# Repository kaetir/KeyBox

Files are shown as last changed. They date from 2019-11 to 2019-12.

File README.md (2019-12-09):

# KeyBox

## Équipe

- Antoine VERSMESSEN
- Clément DUQUENNE
- Édouard DANSETTE
- Sébastien WILLEMETZ
- Thibault DESPREZ

## Idées

*gestionnaire de mot de passe physique*

- Utiliser un raspi 0w si possible + usb board
- Écran
    - Oled
- Authentification 
    - Boutons 
    - Lecteur d'empreintes
- Navigation 
    - Boutons

On branche le raspi sur un pc ou un tel pour entrer le mot de passe en auto

Ajout des mots de passe par wifi et/ou physique

Stockage des mots de passe chiffré dans un Json

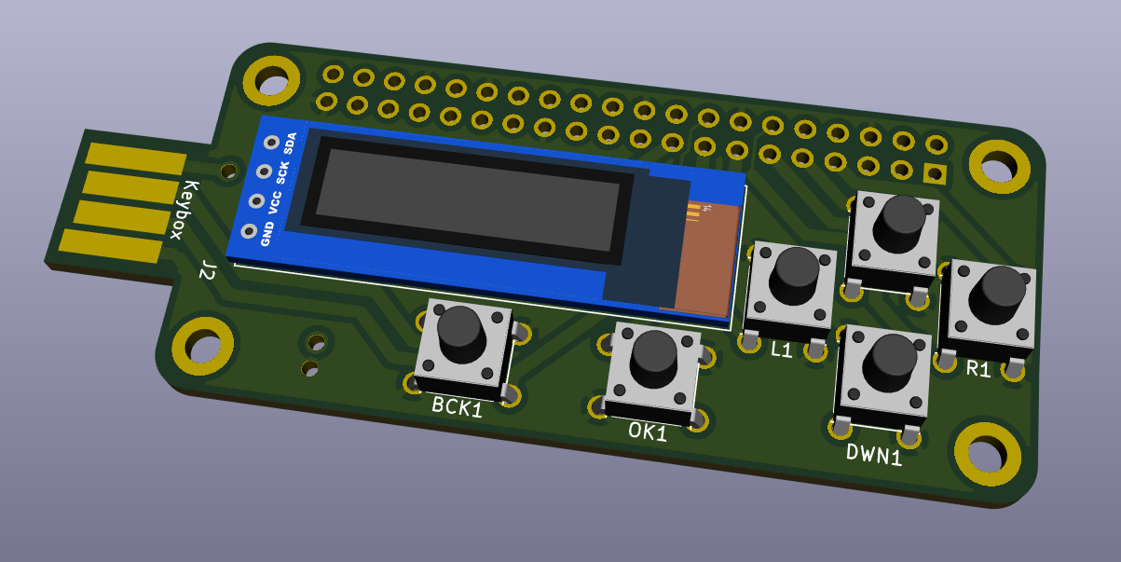
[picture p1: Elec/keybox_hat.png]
hat


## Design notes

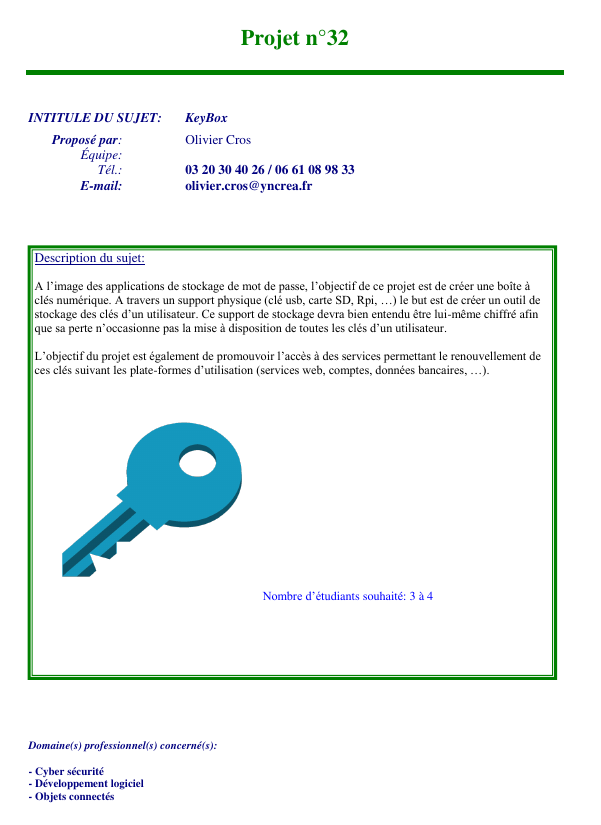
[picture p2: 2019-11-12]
fiche_proG.png

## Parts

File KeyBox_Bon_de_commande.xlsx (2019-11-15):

 | Produit | Quantité | Prix | Frais de port | Site | Lien
 | Boutons | 1 | 2.03 € | 4.99 € | Amazon | https://www.amazon.fr/gp/product/B00H3CVRGY/ref=ox_sc_mini_detail?ie=UTF8&psc=1&smid=A258M9JSP6L6E7
 | Module d'affichage OLED | 1 | 8.89 € |  | Amazon | https://www.amazon.fr/MakerHawk-Module-daffichage-SSD1306-Arduino/dp/B076BJZ42H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
 | Capteur d'empreintes | 1 | 7.14 € | 2.04 € | Aliexpress | https://fr.aliexpress.com/item/4000003758066.html
 | USB board | 1 | 3.29 € | inclus | Banggood | https://fr.banggood.com/BadUSB-Zero-Quick-Plug-For-Raspberry-Pi-Zero-v1_3-Zero-W-p-1305226.html?gmcCountry=FR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
 | Raspberry Pi Zero W | 1 | 10.44 € | 4.96 € | Kubii | https://www.kubii.fr/les-cartes-raspberry-pi/1851-raspberry-pi-zero-w-kubii-3272496006997.html?src=raspberrypi
Total |  | 5 | 31.79 € | 11.99 €
Prix total | 43.78 €

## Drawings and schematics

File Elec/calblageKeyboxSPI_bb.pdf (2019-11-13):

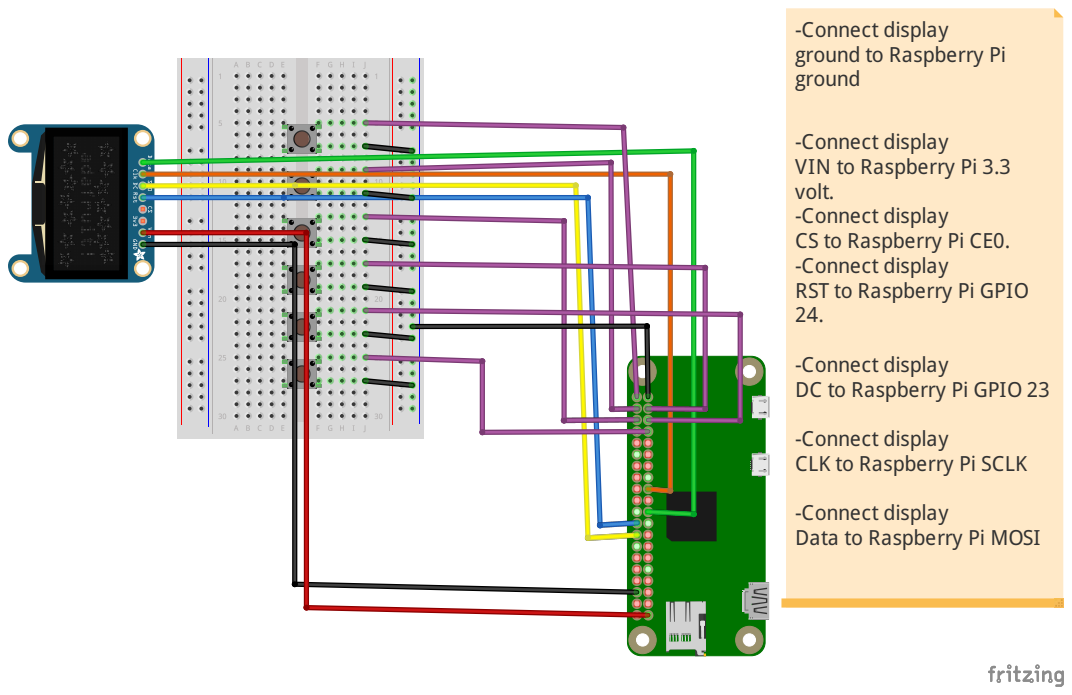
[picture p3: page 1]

-Connect display
ground to Raspberry Pi
ground

VIN to Raspberry Pi 3.3
volt.
CS to Raspberry Pi CE0.
RST to Raspberry Pi GPIO

DC to Raspberry Pi GPIO 23

CLK to Raspberry Pi SCLK

Data to Raspberry Pi MOSI

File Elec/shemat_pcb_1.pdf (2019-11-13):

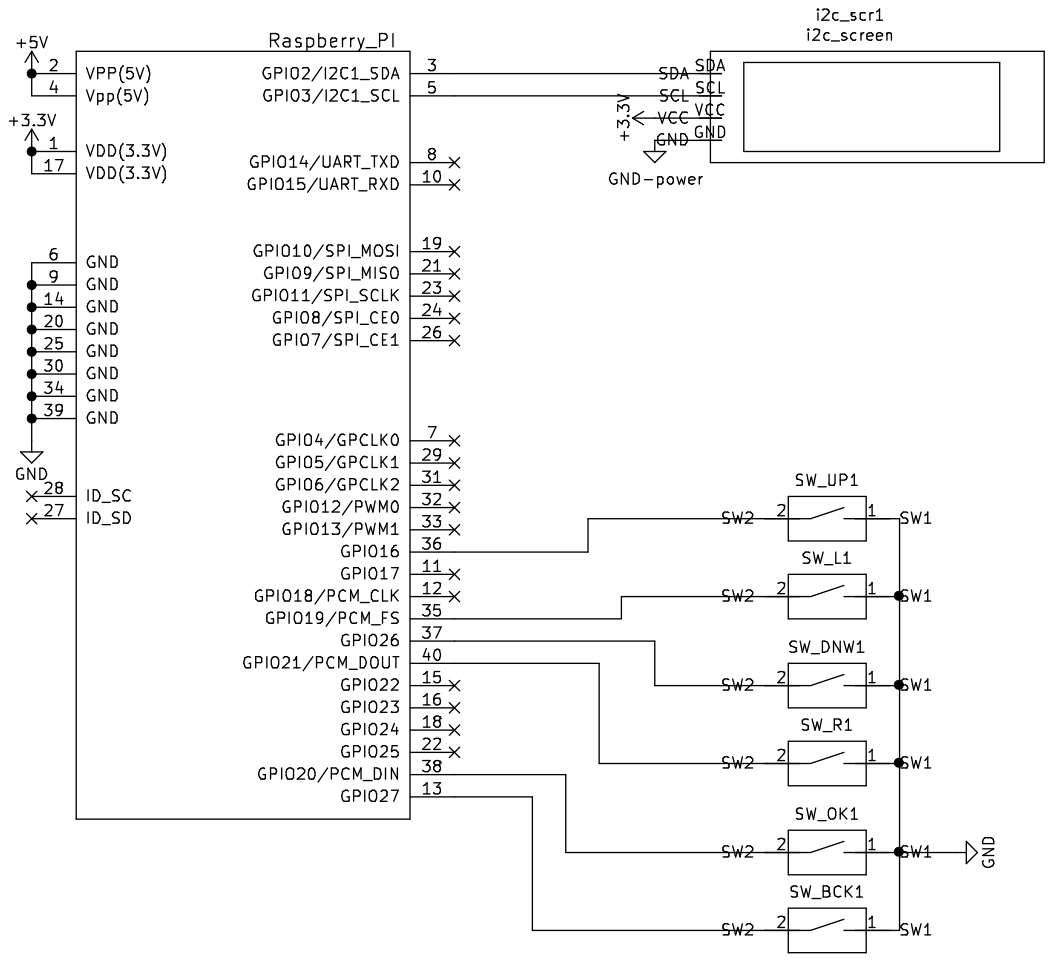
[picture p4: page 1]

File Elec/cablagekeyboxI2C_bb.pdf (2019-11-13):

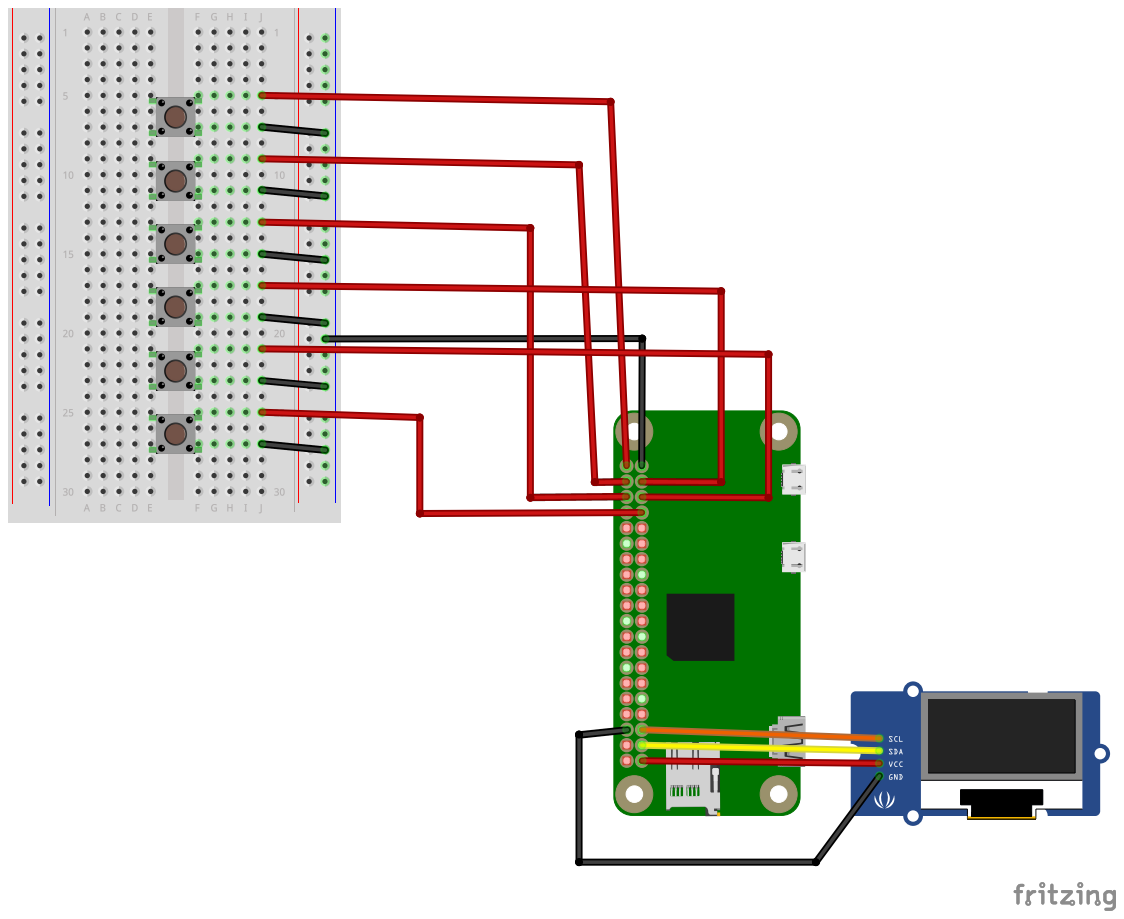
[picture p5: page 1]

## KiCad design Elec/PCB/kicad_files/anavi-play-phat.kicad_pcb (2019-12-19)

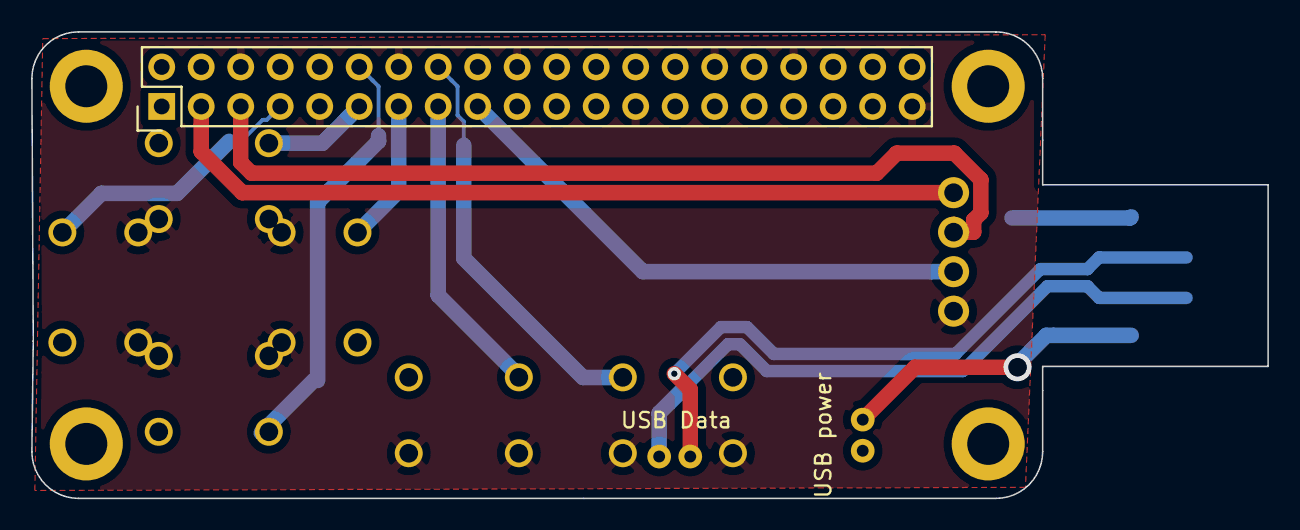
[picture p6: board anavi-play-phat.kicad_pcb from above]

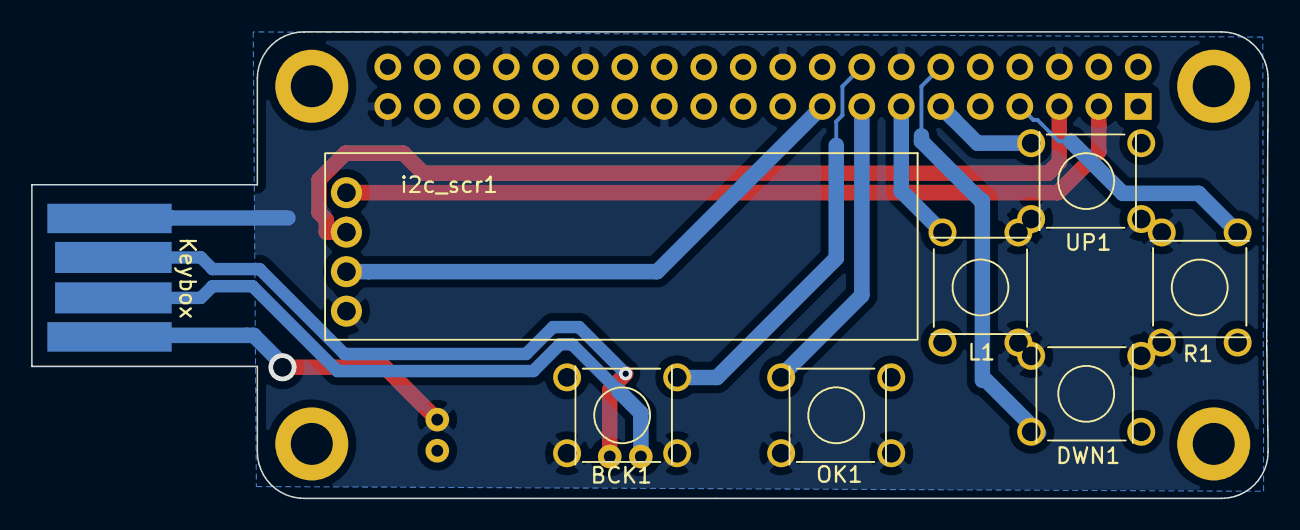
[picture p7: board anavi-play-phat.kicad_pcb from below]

Board: 2 copper layers, 79.5 x 30.0 mm, 15 parts (8 on the bottom side), 11 nets.

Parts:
BCK1: boutton_6mx6m; boutton__6mx6m
DWN1: boutton_6mx6m; boutton__6mx6m
J1: USB Data; header 2m spaced
J2: USB power; header 2m spaced
J2#2: USB_A_PLUG; CONN-USB-A-PCB-TRACES
L1: boutton_6mx6m; boutton__6mx6m
OK1: boutton_6mx6m; boutton__6mx6m
R1: boutton_6mx6m; boutton__6mx6m
RASP_CONN1: Raspberry_PI; Pin_Header_Straight_2x20
REF1, REF2, REF3, REF4: MountingHole_2.7mm_M2.5_DIN965_Pad
UP1: boutton_6mx6m; boutton__6mx6m
i2c_scr1: i2c_screen

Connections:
+3V3: RASP_CONN1.1, RASP_CONN1.17, i2c_scr1.VCC
+5V: J2.1, J2#2.1, RASP_CONN1.2, RASP_CONN1.4
GND: BCK1.1, DWN1.1, J2.2, J2#2.4, L1.1, OK1.1, R1.1, RASP_CONN1.6, RASP_CONN1.9, RASP_CONN1.14, RASP_CONN1.20, RASP_CONN1.25, RASP_CONN1.30, RASP_CONN1.34, RASP_CONN1.39, UP1.1, i2c_scr1.GND
unnamed: BCK1.2, RASP_CONN1.16
unnamed: DWN1.2, RASP_CONN1.12
unnamed: L1.2, RASP_CONN1.13
unnamed: OK1.2, RASP_CONN1.15
unnamed: R1.2, RASP_CONN1.7
unnamed: RASP_CONN1.3, i2c_scr1.SDA
unnamed: RASP_CONN1.5, i2c_scr1.SCL
unnamed: RASP_CONN1.11, UP1.2

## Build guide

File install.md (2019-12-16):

 # Installation de KeyBox

## Initialisation

```bash
sudo raspi config
# change local and keyboard layout 
# enable i2c and GPIO
sudo apt-get update
sudo apt-get dist-upgrade
sudo reboot
```

## Module à installer

``` bash
sudo apt install python3-pip git python3-pillow
sudo pip3 install rpi.gpio Adafruit_GPIO Adafruit_SSD1306 pillow

```

## Config hotspot

https://github.com/billz/raspap-webgui

```bash
curl -sL https://install.raspap.com | bash
reboot
```

```bash
sudo nano /etc/hostapd/hostapd.conf
```

retirer les commentaires et config le conrtycode et le ssid ainsi que le wpa_passphrase

```bash
reboot
```

se connecter au réseau et aller sur l'adresse ip 10.3.141.1

se connecter avec 

`user : admin`

`password : secret`

changer dans config hotspot 

onglet sécurité :arrow_forward:

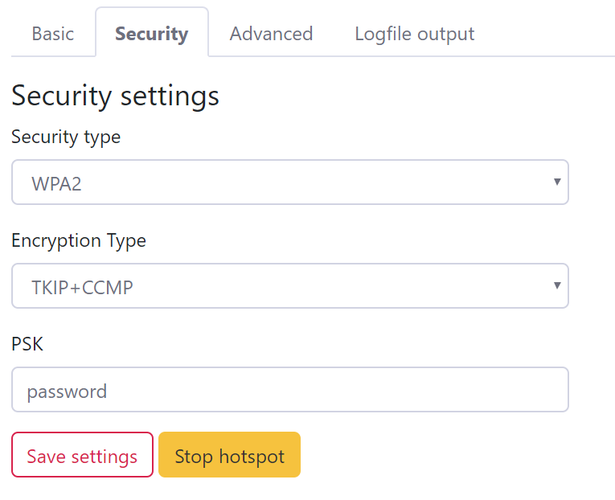
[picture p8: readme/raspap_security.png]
raspa conf


```bash
sudo systemctl disable lighttpd
sudo systemctl disable raspap 
reboot
```

## Install Keybox

```bash
git clone https://github.com/kaetir/KeyBox
```

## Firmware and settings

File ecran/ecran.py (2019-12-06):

import Adafruit_GPIO.SPI as SPI
import Adafruit_SSD1306

from PIL import Image
from PIL import ImageDraw
from PIL import ImageFont
 



class Ecran:
    nb=0
    nbCols = 21
    nbLign = 3
    lignes= [i*10 for i in range(nbLign)]
    colones = [i * 6 for i in range(nbCols)]

    def __init__(self):
        self.disp = Adafruit_SSD1306.SSD1306_128_32(rst=24) 
        self.disp.begin()
        self.disp.clear()
        self.disp.display()
        self.font = ImageFont.load_default()
        self.image = Image.new('1', (self.disp.width, self.disp.height))
        self.draw = ImageDraw.Draw(self.image)

    def display(self):
        self.disp.image(self.image)
        self.disp.display()


    def draw_text(self, text, ligne, col = 0):
        if ligne > self.nbLign-1 or col > self.nbCols - 1:
            return
        self.draw.text((self.colones[col]+2, self.lignes[ligne]),text,
                       font=self.font, fill=255)

    def clear_scr(self):
        self.image = Image.new('1', (self.disp.width, self.disp.height))
        self.draw= ImageDraw.Draw(self.image)
        self.disp.clear()
        self.disp.display()
    
    
    def curs(self,x,y):
        # x et y sont en colones lignes
        if y < self.nbLign:
            self.draw_text(">", x, y)
            self.disp.image(self.image)
            #nb+=1


            
if __name__ == "__main__":
    monEcran = Ecran()
    monEcran.draw_text("ta maman", 0,0)
    monEcran.display()
    

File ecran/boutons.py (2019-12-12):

import time
import RPi.GPIO as GPIO


class Boutons:
    # pin GPIO
    pinBtn = [18, 27, 17, 4, 22, 23]

    # place des bouton dans le tableau pinBtn
    mapping = {
        "DOWN": 0,
        "LEFT": 1,
        "UP": 2,
        "RIGHT": 3,
        "OK": 4,
        "BACK": 5
    }

    def __init__(self):
        """
        @summary constructeur 
        """
        GPIO.setmode(GPIO.BCM)
        for i in self.pinBtn:
            GPIO.setup(self.pinBtn, GPIO.IN, pull_up_down=GPIO.PUD_UP)
        self.getState()

    def getState(self):
        """
        @summary lit l'état des boutons et le stock dans la variable status
        """
        self.status = [GPIO.input(pin) for pin in self.pinBtn]

    def getStatus(self, bouton: str):
        """
        @summary lit l'état d'un bouton par son string
        @param bouton: str -> string du nom du bouton cf var mapping
        """
        self.getState()
        if bouton in self.mapping:
            return self.status[self.mapping[bouton]]
        else:
            print("bad index")

    def while_pressed(self, button: str, timeout: int = 200):
        """
        @summary bloque tant que le bouton est pressé ou que le timeout n'est pas passé
        @param bouton: str -> string du nom du bouton cf var mapping
        @param timeout: int -> milisecondes avant de reconsidéré un appui
        """
        t0 = int(time.time_ns())
        while int(time.time_ns()) < int(t0 + 1000000 * timeout):
            self.getState()
            if self.status[self.mapping[button]]:
                return

    def test_mapping(self):
        """
        @summary permet de verifier le dictionnaire mapping 
        """
        while True:
            for b in self.mapping:
                print("{} : {}\t".format(b, self.getStatus(b)), end='')
            print()


if __name__ == "__main__":
    mesBoutons = Boutons()
    mesBoutons.test_mapping()

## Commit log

2019-10-14 ajout du readme et des idées
2019-10-14 ajout des fonctions de base et de test
2019-10-15 code qui permet de cryp et decrypt des mdp a partir d'un mot de passe maitre
2019-10-15 ajout d'un code pour écran spi
2019-10-16 ouverture et modification de json
2019-10-16 ajout du fichier de test
2019-10-16 passage a des fonctions et test
2019-10-16 ajout de test de code pour les GPIO
2019-10-17 Le cablage des ecrans I2C et SPI et boutons
    [cablagekeyboxI2C.fzz, calblageKeyboxSPI.fzz]
2019-10-17 update des shemats
    [cablagekeyboxI2C.fzz, calblageKeyboxSPI.fzz]
2019-10-18 ajout du bout de code pour le hotspot
2019-11-13 fusion des fichiers
2019-11-13 actualisation des cablages I2C et SPI
2019-11-13 PCB test1
    [anavi-play-phat-B_Cu.gbl, anavi-play-phat-Edge_Cuts.gm1, anavi-play-phat-F_Cu.gtl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]
2019-11-13 ajout de l'écran
2019-11-14 Générateur phrase
    [KeyBox_Bon_de_commande.xlsx]
2019-11-15 ajout de la lecture par un fichier txt
2019-11-16 PCB v2
    [anavi-play-phat-B_Cu.gbl, anavi-play-phat-Edge_Cuts.gm1, anavi-play-phat-F_Cu.gtl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]
2019-12-02 Il faut refaire le pcb avec le port usb de l'autre coté
    [anavi-play-phat.sch]
2019-12-02 déplacement de la fonction dico dans le genpasswd
    et réencodage du dico en utf8
2019-12-03 ajoute des tests de mapping boutons
2019-12-03 PCB v3 correction USB
    [anavi-play-phat.kicad_pcb, anavi-play-phat.sch]
2019-12-03 pcb mieux
    [anavi-play-phat.kicad_pcb]
2019-12-03 j'avais pas save déso
    [anavi-play-phat.kicad_pcb, anavi-play-phat.sch]
2019-12-04 les changements post zyhto
2019-12-06 export du pcb version 2.5
    [anavi-play-phat.kicad_pcb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]
2019-12-10 le pcb corrigé pour une vrai prod
    [anavi-play-phat.kicad_pcb]
2019-12-12 Le joli pcb
    [anavi-play-phat.kicad_pcb, anavi-play-phat.sch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]
2019-12-12 les menus quasi terminés
2019-12-13 pcb et readme
    [anavi-play-phat.kicad_pcb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]
2019-12-18 IL EST ECRIT QUE SEUL LONK PEUT VAINCRE GANON
    [anavi-play-phat.kicad_pcb]
2019-12-19 Tout plein de modifs
    [anavi-play-phat.kicad_pcb, anavi-play-phat.sch]
